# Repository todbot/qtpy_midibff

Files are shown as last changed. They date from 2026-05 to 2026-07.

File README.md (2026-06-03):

# qtpy_midibff

QTPy MIDI BFF — a small MIDI interface board for QTPy / Xiao class boards (RP2040 or compatible).
The board breaks out the host MCU's hardware UART to standard MIDI IN and MIDI OUT jacks (TRS or 5-pin DIN).

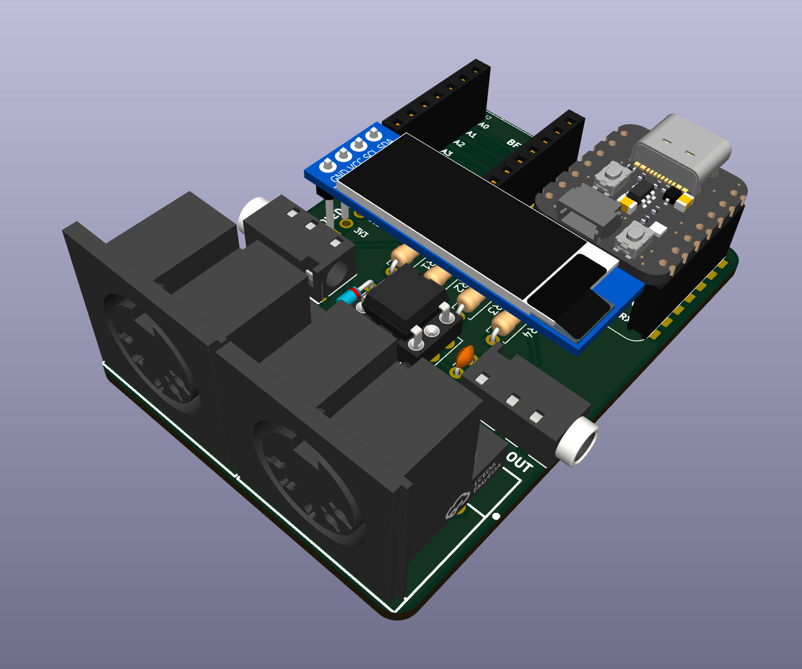
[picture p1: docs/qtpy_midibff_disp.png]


## Hardware

The PCB is meant for easy assembly using only through-hole components. 
It is essentialy a QTPy "doubler" with a standard MIDI In and MIDI Out circuit, 
with a 4-pin I2C header for a standard OLED display (usually 128x32 SSD1306).

## Assembling

_Coming soon._

## Arduino sketches

Requires [arduino-pico](https://arduino-pico.readthedocs.io/en/latest/install.html) board core.

Set **Tools > USB Stack: Adafruit TinyUSB** before uploading any sketch.

Libraries needed (Arduino Library Manager):
- [Adafruit TinyUSB](https://github.com/adafruit/Adafruit_TinyUSB_Arduino)
- [MIDI Library](https://github.com/FortySevenEffects/arduino_midi_library)
- [Adafruit SSD1306](https://github.com/adafruit/Adafruit_SSD1306) + [Adafruit GFX Library](https://github.com/adafruit/Adafruit-GFX-Library) _(OLED sketches only)_
- [Adafruit SPIFlash](https://github.com/adafruit/Adafruit_SPIFlash) + [SdFat - Adafruit Fork](https://github.com/adafruit/SdFat) + [ArduinoJson](https://arduinojson.org) _(MSC sketch only)_

### `midi_interface` — USB-MIDI ↔ UART-MIDI bridge

[`arduino/midi_interface/`](arduino/midi_interface/)

Forwards all MIDI between USB and UART in both directions. Includes scaffolding to filter or
transform messages — uncomment the examples or add your own:

- Drop realtime messages (clock, active sensing, etc.)
- Transpose notes on a channel
- Remap channels

```
arduino-cli compile \
  --fqbn rp2040:rp2040:adafruit_qtpy:usbstack=tinyusb \
  arduino/midi_interface
```

SysEx messages up to 127 bytes are forwarded. See the source for notes on larger SysEx.

### `midi_interface_oled` — bridge with OLED display

[`arduino/midi_interface_oled/`](arduino/midi_interface_oled/)

Same bridge as `midi_interface`, with a 128x32 SSD1306 I2C OLED that displays each incoming
message. Realtime messages (clock, active sensing) are forwarded but not shown, to avoid flicker.

```
arduino-cli compile \
  --fqbn rp2040:rp2040:adafruit_qtpy:usbstack=tinyusb \
  arduino/midi_interface_oled
```

### `midi_interface_msc` — bridge with USB flash drive and config file

[`arduino/midi_interface_msc/`](arduino/midi_interface_msc/)

Extends `midi_interface_oled` with a USB Mass Storage device backed by the RP2040's internal
flash (the filesystem partition). The drive contains a `config.json` file that controls runtime
behaviour — no recompile needed to change settings.

```json
{
  "name": "MIDI BFF",
  "manufacturer": "todbot",
  "filter_realtime": false,
  "transpose": 0
}
```

Edit `config.json` on the drive, eject it, then reset the board to apply the new settings.
The `filter_realtime` and `transpose` fields are applied in both directions.

Requires a board Flash Size setting that includes a 1MB filesystem partition. Compile commands for each supported board:

```
# QTPy RP2040 (8MB flash)
arduino-cli compile \
  --fqbn rp2040:rp2040:adafruit_qtpy:usbstack=tinyusb,flash=8388608_1048576 \
  arduino/midi_interface_msc

# Xiao RP2040 (2MB flash)
arduino-cli compile \
  --fqbn rp2040:rp2040:seeed_xiao_rp2040:usbstack=tinyusb,flash=2097152_1048576 \
  arduino/midi_interface_msc
```

### `midi_interface_simple` — simplified bridge for learners

[`arduino/midi_interface_simple/`](arduino/midi_interface_simple/)

Same USB-MIDI ↔ UART-MIDI bridge with the same filter/transform scaffolding, but with SysEx
handling and advanced notes removed. A good starting point if you just want to read and modify
the forwarding logic without the extra complexity.

```
arduino-cli compile \
  --fqbn rp2040:rp2040:adafruit_qtpy:usbstack=tinyusb \
  arduino/midi_interface_simple
```

## CircuitPython sketches

Requires CircuitPython 9+ firmware on the board.

Libraries needed:
- [tmidi](https://github.com/todbot/CircuitPython_TMIDI) — copy `tmidi.py` to `/lib/` on your device or install with `circup tmidi`
- [adafruit_ssd1306](https://github.com/adafruit/Adafruit_CircuitPython_SSD1306) — install with `circup install adafruit_ssd1306` _(OLED sketches only)_

### `midi_interface` — USB-MIDI ↔ UART-MIDI bridge

[`circuitpython/midi_interface/`](circuitpython/midi_interface/)

Forwards all MIDI between USB and UART in both directions. Same filter/transform scaffolding
as the Arduino version — uncomment the examples or add your own:

- Drop realtime messages (clock, active sensing, etc.)
- Transpose notes on a channel
- Remap channels

SysEx messages up to 127 bytes are forwarded. Increase the `sysex_buf_*` bytearray sizes in
the source to raise the limit.

Copy `code.py` to the root of your device, or copy the whole `midi_interface/` folder and
rename `code.py` to suit.

### `midi_interface_oled` — bridge with OLED display

[`circuitpython/midi_interface_oled/`](circuitpython/midi_interface_oled/)

Same bridge as `midi_interface`, with a 128x32 SSD1306 I2C OLED that displays each incoming
message. Realtime messages are forwarded but not shown, to avoid flicker. The sketch continues
as a plain MIDI bridge if no display is connected.

Copy `code.py` to the root of your device, or copy the whole `midi_interface_oled/` folder and
rename `code.py` to suit.

## Hardware

Schematic and PCB in `schematics/midi_bff/` (KiCad).

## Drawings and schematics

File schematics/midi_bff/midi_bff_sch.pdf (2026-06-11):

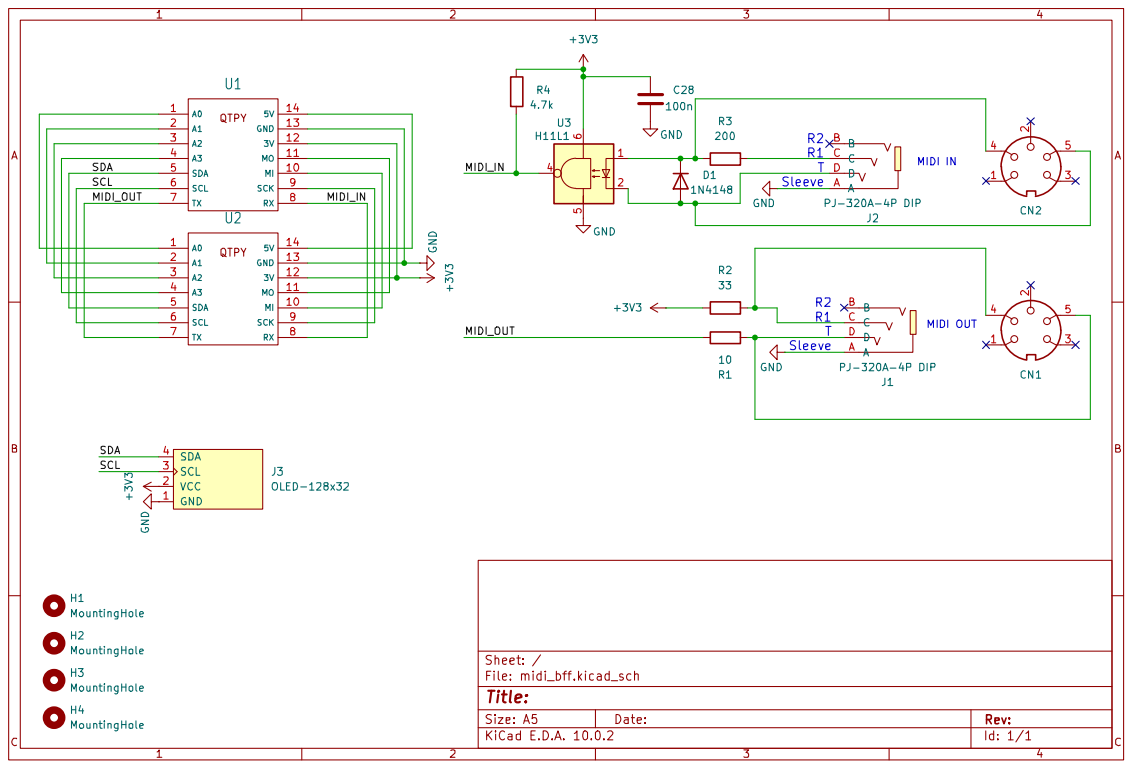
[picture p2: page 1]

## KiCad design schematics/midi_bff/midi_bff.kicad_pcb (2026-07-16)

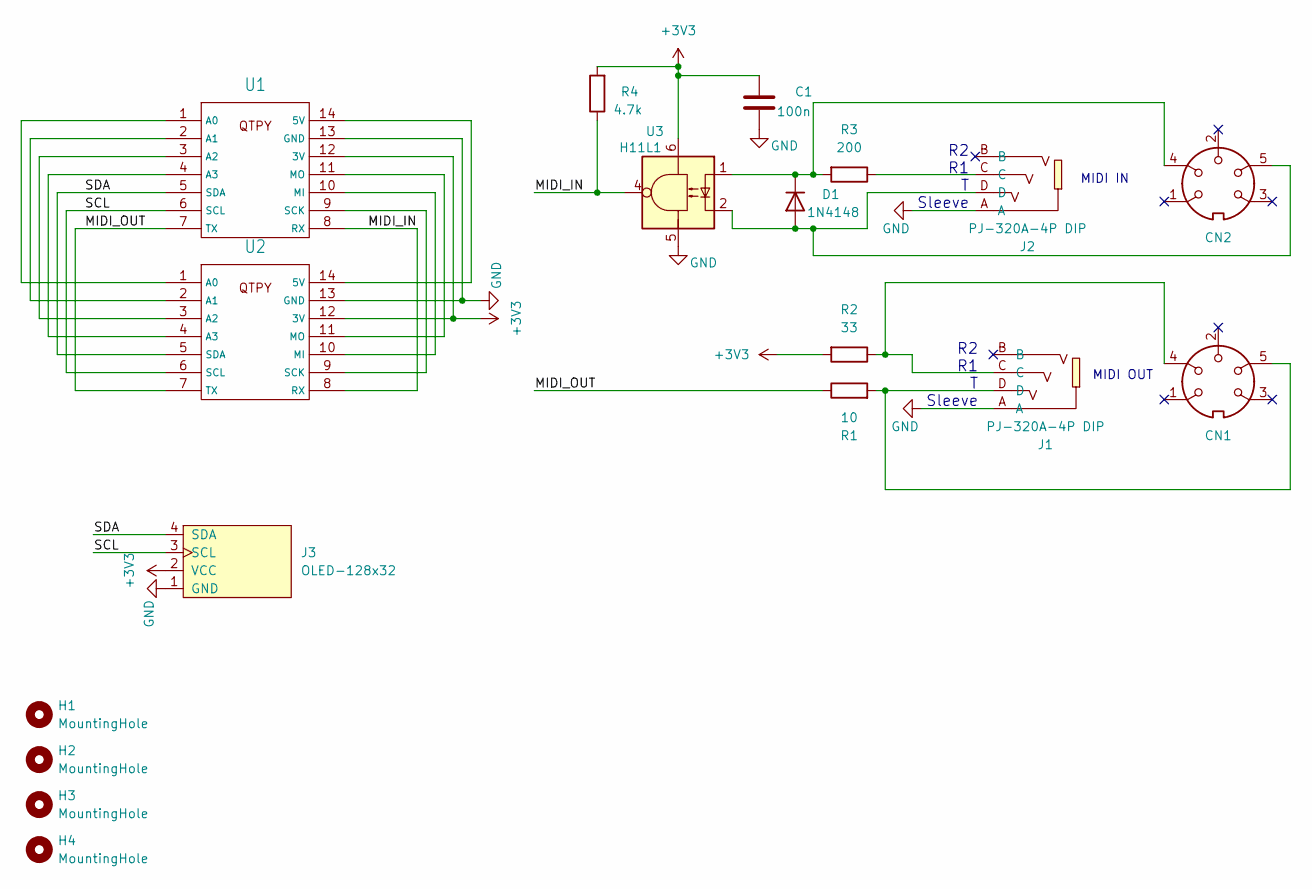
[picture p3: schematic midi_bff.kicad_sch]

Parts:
C1: 100n; C_Disc_D3.0mm_W1.6mm_P2.50mm; LCSC Part C1590
CN1, CN2: DIN-504; CONN-TH_DIN-504-M10; MPN DIN-504; LCSC Part C23689428
D1: 1N4148; D_DO-34_SOD68_P7.62mm_Horizontal; LCSC Part C81598
H1, H2, H3, H4: MountingHole; MountingHole_2.5mm
J1, J2: PJ-320A-4P DIP; AUDIO-TH_PJ-320A-4P-DIP; LCSC Part C18185602
J3: OLED-128x32
R1: 10; R_Axial_DIN0207_L6.3mm_D2.5mm_P7.62mm_Horizontal; LCSC Part C22859
R2: 33; R_Axial_DIN0207_L6.3mm_D2.5mm_P7.62mm_Horizontal; LCSC Part C23140
R3: 200; R_Axial_DIN0207_L6.3mm_D2.5mm_P7.62mm_Horizontal; LCSC Part C8218
R4: 4.7k; R_Axial_DIN0207_L6.3mm_D2.5mm_P7.62mm_Horizontal; LCSC Part C23162
U1, U2: QTPY-DIP
U3: H11L1; DIP-6_W7.62mm_Socket_LongPads; LCSC C78589

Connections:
+3V3: C1.1, J3.2 (VCC), R2.2, R4.2, U1.12 (3V), U2.12 (3V), U3.6
/MIDI_IN: R4.1, U1.8 (RX), U2.8 (RX), U3.4
/MIDI_OUT: R1.1, U1.7 (TX), U2.7 (TX)
/SCL: J3.3 (SCL), U1.6 (SCL), U2.6 (SCL)
/SDA: J3.4 (SDA), U1.5 (SDA), U2.5 (SDA)
GND: C1.2, J1.A, J2.A, J3.1 (GND), U1.13 (GND), U2.13 (GND), U3.5
unnamed: CN1.4, J1.C, R2.1
unnamed: CN1.5, J1.D, R1.2
unnamed: CN2.5, D1.2 (A), J2.D, U3.2
unnamed: CN2.4, D1.1 (K), R3.2, U3.1
unnamed: J2.C, R3.1
unnamed: U1.14 (5V), U2.14 (5V)
unnamed: U1.1 (A0), U2.1 (A0)
unnamed: U1.2 (A1), U2.2 (A1)
unnamed: U1.3 (A2), U2.3 (A2)
unnamed: U1.4 (A3), U2.4 (A3)
unnamed: U1.10 (MI), U2.10 (MI)
unnamed: U1.11 (MO), U2.11 (MO)
unnamed: U1.9 (SCK), U2.9 (SCK)

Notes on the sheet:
MIDI OUT
R2 R1 T Sleeve
MIDI IN

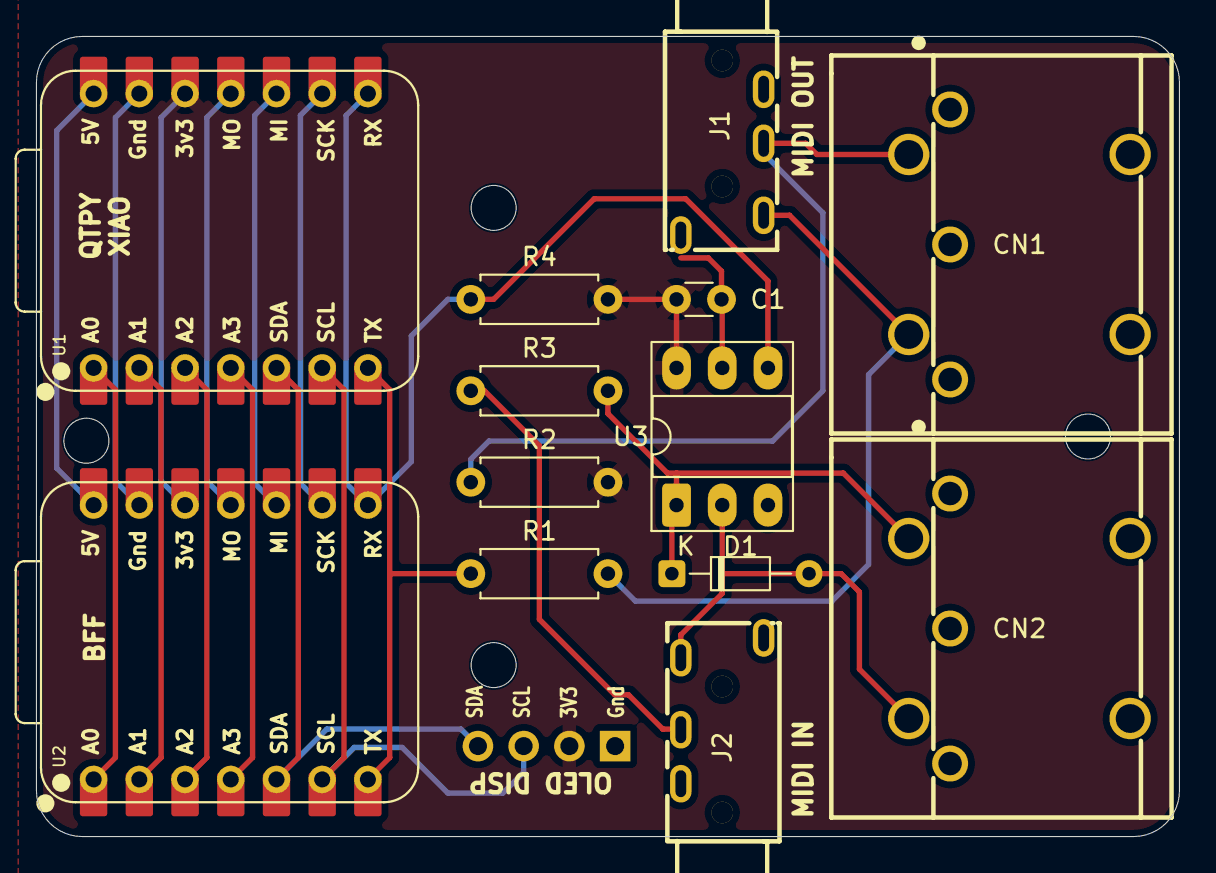
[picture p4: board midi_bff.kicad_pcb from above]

Board: 2 copper layers, 63.5 x 44.4 mm, 18 parts (0 on the bottom side), 19 nets.

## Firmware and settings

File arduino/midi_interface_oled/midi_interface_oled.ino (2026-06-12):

/**
 * midi_interface_oled.ino -- USB-MIDI <-> UART MIDI bridge with SSD1306 OLED display
 * 30 May 2026 - @todbot / Tod Kurt
 * Part of https://github.com/todbot/qtpy_midibff
 *
 * Forwards all MIDI between USB and UART in both directions,
 * and displays each incoming message on a 128x32 I2C OLED.
 * Realtime messages (Clock, ActiveSensing, etc.) are forwarded but not shown,
 * to prevent display flicker. If you're sending dense MIDI (e.g. clock),
 * uncomment the realtime filter lines in filter_usb_to_uart() / filter_uart_to_usb()
 * to drop them before forwarding too.
 *
 * Libraries needed (all available via Library Manager):
 * - Adafruit TinyUSB   -- https://github.com/adafruit/Adafruit_TinyUSB_Arduino
 * - MIDI Library       -- https://github.com/FortySevenEffects/arduino_midi_library
 * - Adafruit SSD1306   -- https://github.com/adafruit/Adafruit_SSD1306
 * - Adafruit GFX Library -- https://github.com/adafruit/Adafruit-GFX-Library
 * - Adafruit NeoPixel  -- https://github.com/adafruit/Adafruit_NeoPixel
 *
 * To install libraries with arduino-cli:
 *   arduino-cli lib install "Adafruit TinyUSB Library" "MIDI Library" \
 *     "Adafruit SSD1306" "Adafruit GFX Library" "Adafruit NeoPixel"
 *
 * To upload:
 * - Board: QTPy RP2040, Xiao RP2040, or similar
 * - Tools > USB Stack: Adafruit TinyUSB
 *
 * To compile on the commandline with arduino-cli for Adafruit QTPy RP2040:
 *   arduino-cli compile \
 *    --fqbn rp2040:rp2040:adafruit_qtpy:usbstack=tinyusb \
 *   arduino/midi_interface_oled
 *
 * OLED: 128x32 SSD1306 on the standard I2C port (SDA/SCL), address 0x3C.
 * Change OLED_ADDR to 0x3D if your module uses the alternate address.
 *
 * Display examples (128x32, text size 1, two rows):
 *
 *   Note On / Off:          CC:                     Program Change:
 *   ┌────────────────────┐  ┌────────────────────┐  ┌────────────────────┐
 *   │USB NoteOn    ch1   │  │UART CC       ch10  │  │USB PC        ch1   │
 *   │n:C4(60)  v:127     │  │cc:74  val:63       │  │pc:5                │
 *   └────────────────────┘  └────────────────────┘  └────────────────────┘
 *
 *   Pitch Bend:             SysEx:
 *   ┌────────────────────┐  ┌────────────────────┐
 *   │USB PitchBend ch1   │  │UART SysEx          │
 *   │pb:-2048            │  │42 bytes            │
 *   └────────────────────┘  └────────────────────┘
 *
 * SysEx: same behaviour as midi_interface.ino — messages up to 127 bytes are
 * forwarded; larger messages are dropped. See that sketch for details and the
 * MIDI_CREATE_CUSTOM_INSTANCE workaround to raise the limit.
 **/

#include <Adafruit_TinyUSB.h>
#include <MIDI.h>
#include <Adafruit_NeoPixel.h>
#include <Wire.h>
#include <Adafruit_GFX.h>
#include <Adafruit_SSD1306.h>

// change these colors to your preference
const uint32_t COLOR_START            = 0x800080;  // purple
const uint32_t COLOR_USB_TO_UART      = 0x002000;  // green 
const uint32_t COLOR_UART_TO_USB      = 0x000020;  // blue
const uint32_t COLOR_USB_TO_UART_RT   = 0x000A00;  // dim green  (realtime msgs)
const uint32_t COLOR_UART_TO_USB_RT   = 0x00000A;  // dim blue   (realtime msgs)

// PIN_NEOPIXEL is GPIO 12 on both QTPy RP2040 and Xiao RP2040
Adafruit_NeoPixel pixel(1, PIN_NEOPIXEL, NEO_GRB + NEO_KHZ800);
uint32_t led_off_ms = 0;

void led_flash(uint32_t color) {
    pixel.setPixelColor(0, color);
    pixel.show();
    led_off_ms = millis() + 30;
}

// -- OLED
#define SCREEN_WIDTH 128
#define SCREEN_HEIGHT 32
#define OLED_ADDR 0x3C

Adafruit_SSD1306 display(SCREEN_WIDTH, SCREEN_HEIGHT, &Wire, -1);
static bool display_ok = false;

// -- MIDI objects
Adafruit_USBD_MIDI usb_midi;
MIDI_CREATE_INSTANCE(Adafruit_USBD_MIDI, usb_midi, MIDIusb);   // USB MIDI
MIDI_CREATE_INSTANCE(HardwareSerial,     Serial1,   MIDIuart);  // UART MIDI

// --
// Filter / transform functions.
// Called once per message in each direction.
// Return false to drop the message entirely.
// Modify the arguments to transform the message before forwarding.
// --

bool filter_usb_to_uart(midi::MidiType& type, uint8_t& data1, uint8_t& data2, uint8_t& channel) {
    // -- drop all realtime messages (Clock, Start, Stop, Continue, ActiveSensing, Reset)
    // if (type >= midi::Clock) return false;

    // -- drop active sensing only
    // if (type == midi::ActiveSensing) return false;

    // -- transpose notes on channel 1 up one octave
    // if ((type == midi::NoteOn || type == midi::NoteOff) && channel == 1)
    //     data1 = min(127, data1 + 12);

    // -- remap channel 2 -> channel 3
    // if (channel == 2) channel = 3;

    return true;
}

bool filter_uart_to_usb(midi::MidiType& type, uint8_t& data1, uint8_t& data2, uint8_t& channel) {
    // -- drop all realtime messages
    // if (type >= midi::Clock) return false;

    // -- drop active sensing only
    // if (type == midi::ActiveSensing) return false;

    // -- transpose notes on channel 1 up one octave
    // if ((type == midi::NoteOn || type == midi::NoteOff) && channel == 1)
    //     data1 = min(127, data1 + 12);

    return true;
}

// --
// OLED helpers
// --

static const char* midi_type_name(midi::MidiType t) {
    switch (t) {
        case midi::NoteOn:            return "NoteOn";
        case midi::NoteOff:           return "NoteOff";
        case midi::ControlChange:     return "CC";
        case midi::ProgramChange:     return "PC";
        case midi::PitchBend:         return "PitchBend";
        case midi::AfterTouchChannel: return "ChanAT";
        case midi::AfterTouchPoly:    return "PolyAT";
        case midi::SystemExclusive:   return "SysEx";
        case midi::SongPosition:      return "SongPos";
        case midi::SongSelect:        return "SongSel";
        case midi::TuneRequest:       return "Tune";
        case midi::Clock:             return "Clock";
        case midi::Start:             return "Start";
        case midi::Stop:              return "Stop";
        case midi::Continue:          return "Continue";
        case midi::ActiveSensing:     return "ActSens";
        case midi::SystemReset:       return "Reset";
        default:                      return "?";
    }
}

// Fills buf with note name + octave, e.g. "C4", "F#3". buf must be >= 5 bytes.
static void note_str(uint8_t note, char* buf) {
    static const char* names[] = { "C","C#","D","D#","E","F","F#","G","G#","A","A#","B" };
    snprintf(buf, 5, "%s%d", names[note % 12], (note / 12) - 1);
}

// Displays one non-realtime MIDI message.
// src = "USB" or "UART"; type/data1/data2/channel from the MIDI library getters.
static void show_msg(const char* src, midi::MidiType type,
                     uint8_t data1, uint8_t data2, uint8_t channel) {
    if (!display_ok) return;

    char line1[22], line2[22];
    char nname[5];

    // Line 1: source, type name, channel (channel-voice messages only)
    if (type < midi::SystemExclusive)
        snprintf(line1, sizeof(line1), "%s %-9s ch%d", src, midi_type_name(type), channel);
    else
        snprintf(line1, sizeof(line1), "%s %s", src, midi_type_name(type));

    // Line 2: type-specific data
    switch (type) {
        case midi::NoteOn:
        case midi::NoteOff:
            note_str(data1, nname);
            snprintf(line2, sizeof(line2), "n:%s(%d)  v:%d", nname, data1, data2);
            break;
        case midi::ControlChange:
            snprintf(line2, sizeof(line2), "cc:%d  val:%d", data1, data2);
            break;
        case midi::ProgramChange:
            snprintf(line2, sizeof(line2), "pc:%d", data1 + 1);   // display 1-indexed
            break;
        case midi::PitchBend: {
            int16_t pb = (int16_t)(((uint16_t)data2 << 7 | data1) - 8192);
            snprintf(line2, sizeof(line2), "pb:%d", pb);
            break;
        }
        case midi::AfterTouchChannel:
            snprintf(line2, sizeof(line2), "pressure:%d", data1);
            break;
        case midi::AfterTouchPoly:
            note_str(data1, nname);
            snprintf(line2, sizeof(line2), "n:%s  p:%d", nname, data2);
            break;
        case midi::SongPosition:
            snprintf(line2, sizeof(line2), "beat:%d", (uint16_t)(data2 << 7 | data1));
            break;
        case midi::SongSelect:
            snprintf(line2, sizeof(line2), "song:%d", data1 + 1);
            break;
        default:
            line2[0] = '\0';
            break;
    }

    display.clearDisplay();
    display.setCursor(0, 2);
    display.print(line1);
    display.setCursor(0, 18);
    display.print(line2);
    display.display();
}

static void show_sysex(const char* src, uint16_t array_len) {
    if (!display_ok) return;
    char buf[22];
    display.clearDisplay();
    display.setCursor(0, 2);
    snprintf(buf, sizeof(buf), "%s SysEx", src);
    display.print(buf);
    display.setCursor(0, 18);
    // array_len includes leading 0xF0 and trailing 0xF7; show payload byte count
    snprintf(buf, sizeof(buf), "%d bytes", array_len > 2 ? array_len - 2 : 0);
    display.print(buf);
    display.display();
}

// --

void setup() {
#ifdef NEOPIXEL_POWER
    pinMode(NEOPIXEL_POWER, OUTPUT);
    digitalWrite(NEOPIXEL_POWER, HIGH);
#endif
    pixel.begin();
    pixel.clear();
    pixel.setPixelColor(0, COLOR_START);
    pixel.show();

#if defined(ARDUINO_ARCH_RP2040)
    // Serial1.setRX(midi_rx_pin);
    // Serial1.setTX(midi_tx_pin);
#endif
    TinyUSBDevice.setManufacturerDescriptor("todbot");
    TinyUSBDevice.setProductDescriptor("MIDI BFF");
    usb_midi.setStringDescriptor("MIDI BFF");
    usb_midi.begin();
    MIDIusb.begin(MIDI_CHANNEL_OMNI);
    MIDIusb.turnThruOff();
    MIDIuart.begin(MIDI_CHANNEL_OMNI);
    MIDIuart.turnThruOff();

    display_ok = display.begin(SSD1306_SWITCHCAPVCC, OLED_ADDR);
    if (display_ok) {
        display.clearDisplay();
        display.setTextSize(1);
        display.setTextColor(SSD1306_WHITE);
        display.setTextWrap(false);
        display.setCursor(40, 12);   // center "MIDI BFF" on 128x32
        display.print("MIDI BFF");
        display.display();
    }
}

void loop() {
    if (led_off_ms && millis() > led_off_ms) {
        pixel.clear();
        pixel.show();
        led_off_ms = 0;
    }

    // USB -> UART
    while (MIDIusb.read()) {
        midi::MidiType type    = MIDIusb.getType();
        uint8_t        data1   = MIDIusb.getData1();
        uint8_t        data2   = MIDIusb.getData2();
        uint8_t        channel = MIDIusb.getChannel();
        if (type == midi::SystemExclusive) {
            const uint8_t* buf = MIDIusb.getSysExArray();
            if (buf[0] == 0xF0) {
                uint16_t len = MIDIusb.getSysExArrayLength();
                MIDIuart.sendSysEx(len, buf, true);
                show_sysex("USB", len);
                led_flash(COLOR_USB_TO_UART);
            }
        } else {
            if (type < midi::Clock)
                show_msg("USB", type, data1, data2, channel);
            if (type >= midi::Clock) {
                if (!led_off_ms) led_flash(COLOR_USB_TO_UART_RT);
            } else {
                led_flash(COLOR_USB_TO_UART);
            }
            if (filter_usb_to_uart(type, data1, data2, channel))
                MIDIuart.send(type, data1, data2, channel);
        }
    }

    // UART -> USB
    while (MIDIuart.read()) {
        midi::MidiType type    = MIDIuart.getType();
        uint8_t        data1   = MIDIuart.getData1();
        uint8_t        data2   = MIDIuart.getData2();
        uint8_t        channel = MIDIuart.getChannel();
        if (type == midi::SystemExclusive) {
            const uint8_t* buf = MIDIuart.getSysExArray();
            if (buf[0] == 0xF0) {
                uint16_t len = MIDIuart.getSysExArrayLength();
                MIDIusb.sendSysEx(len, buf, true);
                show_sysex("UART", len);
                led_flash(COLOR_UART_TO_USB);
            }
        } else {
            if (type < midi::Clock)
                show_msg("UART", type, data1, data2, channel);
            if (type >= midi::Clock) {
                if (!led_off_ms) led_flash(COLOR_UART_TO_USB_RT);
            } else {
                led_flash(COLOR_UART_TO_USB);
            }
            if (filter_uart_to_usb(type, data1, data2, channel))
                MIDIusb.send(type, data1, data2, channel);
        }
    }
}

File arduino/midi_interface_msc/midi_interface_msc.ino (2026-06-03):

/**
 * midi_interface_msc.ino -- USB-MIDI <-> UART MIDI bridge + USB MSC flash drive + SSD1306 OLED
 * 02 Jun 2026 - @todbot / Tod Kurt
 * Part of https://github.com/todbot/qtpy_midibff
 *
 * Extends midi_interface_oled with a USB Mass Storage device backed by the RP2040's
 * internal flash (the filesystem half of the flash). A config.json file on that drive
 * controls runtime behaviour: device name, realtime filtering, and note transposition.
 * The drive appears on the host as a small FAT volume. Edit config.json, eject the
 * drive, then reset the board to apply new settings.
 *
 * Libraries needed (all available via Library Manager):
 * - Adafruit TinyUSB    -- https://github.com/adafruit/Adafruit_TinyUSB_Arduino
 * - MIDI Library        -- https://github.com/FortySevenEffects/arduino_midi_library
 * - Adafruit SSD1306    -- https://github.com/adafruit/Adafruit_SSD1306
 * - Adafruit GFX Library-- https://github.com/adafruit/Adafruit-GFX-Library
 * - Adafruit SPIFlash   -- https://github.com/adafruit/Adafruit_SPIFlash
 * - SdFat - Adafruit Fork -- https://github.com/adafruit/SdFat
 * - ArduinoJson         -- https://arduinojson.org
 *
 * To install libraries with arduino-cli:
 *   arduino-cli lib install "Adafruit TinyUSB Library" "MIDI Library" \
 *     "Adafruit SSD1306" "Adafruit GFX Library" \
 *     "Adafruit SPIFlash" "SdFat - Adafruit Fork" "ArduinoJson"
 *
 * Board setup:
 * - Board: QTPy RP2040 or Xiao RP2040 (or compatible RP2040 board)
 * - Tools > USB Stack: Adafruit TinyUSB
 * - Tools > Flash Size: choose an option with 1MB FS  ← must include a FS partition
 *   QTPy RP2040 (8MB flash): "8MB (Sketch: 7MB, FS: 1MB)"
 *   Xiao RP2040  (2MB flash): "2MB (Sketch: 1MB, FS: 1MB)"
 *
 * To compile on the commandline with arduino-cli:
 *   QTPy RP2040 (8MB flash):
 *     arduino-cli compile \
 *       --fqbn rp2040:rp2040:adafruit_qtpy:usbstack=tinyusb,flash=8388608_1048576 \
 *       arduino/midi_interface_msc
 *   Xiao RP2040 (2MB flash):
 *     arduino-cli compile \
 *       --fqbn rp2040:rp2040:seeed_xiao_rp2040:usbstack=tinyusb,flash=2097152_1048576 \
 *       arduino/midi_interface_msc
 *
 * config.json format (written to drive on first boot if absent):
 *   {
 *     "name": "MIDI BFF",
 *     "manufacturer": "todbot",
 *     "transforms": []
 *   }
 *
 * Fields:
 *   name         -- USB product name and MIDI port name (max 31 chars)
 *   manufacturer -- USB manufacturer string (max 31 chars)
 *   transforms   -- ordered array of transform objects; up to 8 entries
 *
 * Each transform has a required "dir" and "op" field, plus op-specific fields:
 *
 *   dir: "in"  = UART->USB only
 *        "out" = USB->UART only
 *        "both"= both directions
 *
 *   channel: 1-16 to restrict to one channel; omit for all channels (optional on all ops)
 *
 *   {"dir":"both", "op":"filter",        "type":"realtime"}
 *   {"dir":"both", "op":"filter",        "type":"pitch_bend"}
 *     type values: note_on, note_off, cc, program_change, pitch_bend,
 *                  aftertouch, poly_aftertouch, sysex,
 *                  realtime (all: clock/start/stop/continue/active_sensing/reset),
 *                  clock, active_sensing
 *
 *   {"dir":"out",  "op":"remap_channel", "from":1, "to":3}
 *     from: 1-16 or omit/0 for any channel
 *
 *   {"dir":"both", "op":"transpose",     "semitones":12}
 *     semitones: positive = up, negative = down
 *
 *   {"dir":"in",   "op":"thin_cc",       "interval":4}
 *   {"dir":"in",   "op":"thin_cc",       "cc":74, "interval":8}
 *     interval: pass 1 in every N CC messages (>=2)
 *     cc: restrict to one CC number; omit for all CC
 *
 * A full config.json could look like this:
 *
 * {
 *   "name": "MIDI BFF",
 *   "manufacturer": "todbot",
 *   "transforms": [
 *     {"dir": "both", "op": "filter",        "type": "realtime"},
 *     {"dir": "out",  "op": "remap_channel", "from": 1, "to": 3},
 *     {"dir": "both", "op": "transpose",     "semitones": 12},
 *     {"dir": "in",   "op": "thin_cc",       "interval": 4}
 *   ]
 * }
 *
 * Notes:
 * - Config is read once at boot; edit config.json then reset the board to apply.
 * - During MSC write operations the RP2040 must erase/program internal flash, which
 *   pauses XIP (flash execution) for several milliseconds. MIDI forwarding will miss
 *   bytes during that window. This is expected behaviour.
 * - If flash.size() returns 0 after begin(), the board's Flash Size setting has no
 *   filesystem partition. Check Tools > Flash Size and choose an option that includes FS.
 *
 * OLED: 128x32 SSD1306 on the standard I2C port (SDA/SCL), address 0x3C.
 * Change OLED_ADDR to 0x3D if your module uses the alternate address.
 * If the display is absent or fails to initialize, the sketch continues without it.
 *
 * Display examples (128x32, text size 1):
 *
 *   Normal message:         Config changed:
 *   ┌────────────────────┐  ┌────────────────────┐
 *   │USB NoteOn    ch1   │  │Config saved.       │
 *   │n:C4(60)  v:127     │  │Reset to apply.     │
 *   └────────────────────┘  └────────────────────┘
 *
 * SysEx: messages up to 127 bytes are forwarded; larger messages are dropped.
 * See midi_interface.ino for the MIDI_CREATE_CUSTOM_INSTANCE workaround.
 **/

#include "flash_storage.h"  // must be first: pulls in TinyUSB before SPIFlash
#include <MIDI.h>
#include <Wire.h>
#include <Adafruit_GFX.h>
#include <Adafruit_SSD1306.h>
#include <ArduinoJson.h>
#include "midi_transforms.h"

// -- OLED

#define SCREEN_WIDTH 128
#define SCREEN_HEIGHT 32
#define OLED_ADDR 0x3C

Adafruit_SSD1306 display(SCREEN_WIDTH, SCREEN_HEIGHT, &Wire, -1);
static bool display_ok = false;

// -- MIDI objects

Adafruit_USBD_MIDI usb_midi;
MIDI_CREATE_INSTANCE(Adafruit_USBD_MIDI, usb_midi, MIDIusb);
MIDI_CREATE_INSTANCE(HardwareSerial,     Serial1,   MIDIuart);

// -- Runtime config

struct Config {
    char name[32];
    char manufacturer[32];
};

static Config config;

// --
// Filter / transform — delegate to the transform pipeline loaded from config.json.
// Returns false to drop the message. See midi_transforms.h for the op reference.
// --

bool filter_usb_to_uart(midi::MidiType& type, uint8_t& data1, uint8_t& data2, uint8_t& channel) {
    return apply_transforms(type, data1, data2, channel, DIR_OUT);
}

bool filter_uart_to_usb(midi::MidiType& type, uint8_t& data1, uint8_t& data2, uint8_t& channel) {
    return apply_transforms(type, data1, data2, channel, DIR_IN);
}

// --
// Config helpers
// --

static void load_defaults() {
    strlcpy(config.name,         "MIDI BFF", sizeof(config.name));
    strlcpy(config.manufacturer, "todbot",   sizeof(config.manufacturer));
}
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

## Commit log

2022-07-31 sch brd
    [qtpy_midibff.brd, qtpy_midibff.sch, qtpy_midibff_disp.brd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]
2022-08-06 sigh trs-a/b will kill me
    [qtpy_midibff_disp.brd, qtpy_midibff_disp.sch]
2026-05-10 new take on qtpy_midibff
    [midi_bff.kicad_pcb, midi_bff.kicad_sch]
2026-05-11 sent to production
    [midi_bff.kicad_pcb, midi_bff.kicad_sch]
2026-05-29 add first crack at arduino midi_interface
    [midi_interface.ino]
2026-05-29 new board img
2026-05-29 add circuitpython version of midi_interface
2026-06-11 resize to sch to A5
    [midi_bff.kicad_sch]
2026-06-12 add LED status to all Arduino sketches
    [midi_bff.kicad_sch]
2026-07-16 remove old bad schematic
    [qtpy_midibff.brd, qtpy_midibff.sch, qtpy_midibff_disp.brd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]
2026-07-16 add led blinking on midi
    [midi_bff.kicad_pcb]
